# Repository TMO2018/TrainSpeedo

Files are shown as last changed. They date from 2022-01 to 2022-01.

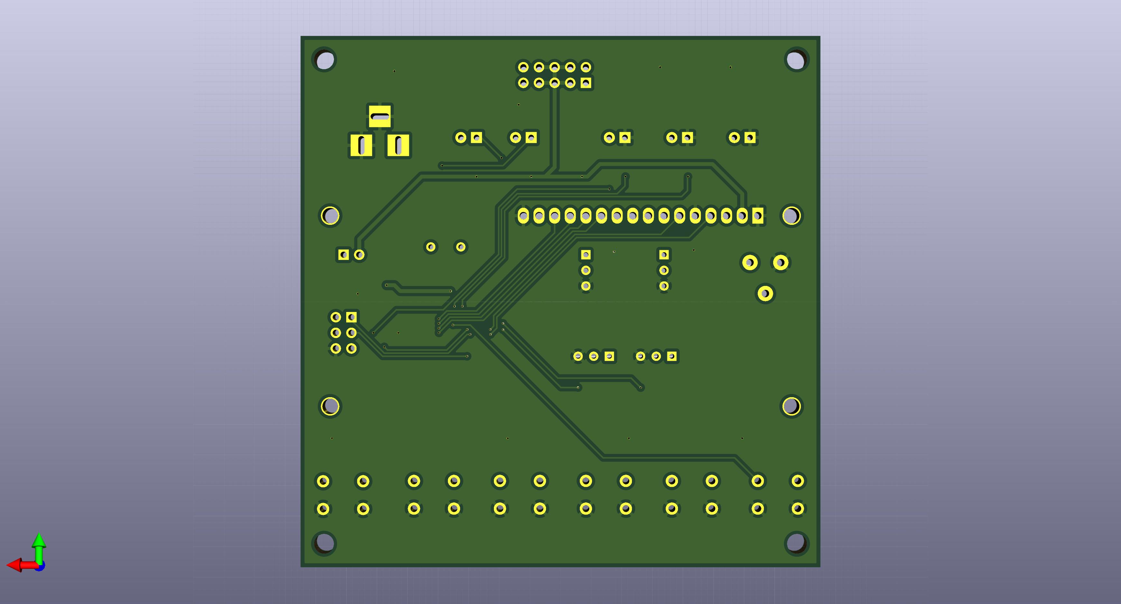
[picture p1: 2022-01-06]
kicad/Rev1_0a/pic/2_back.jpg

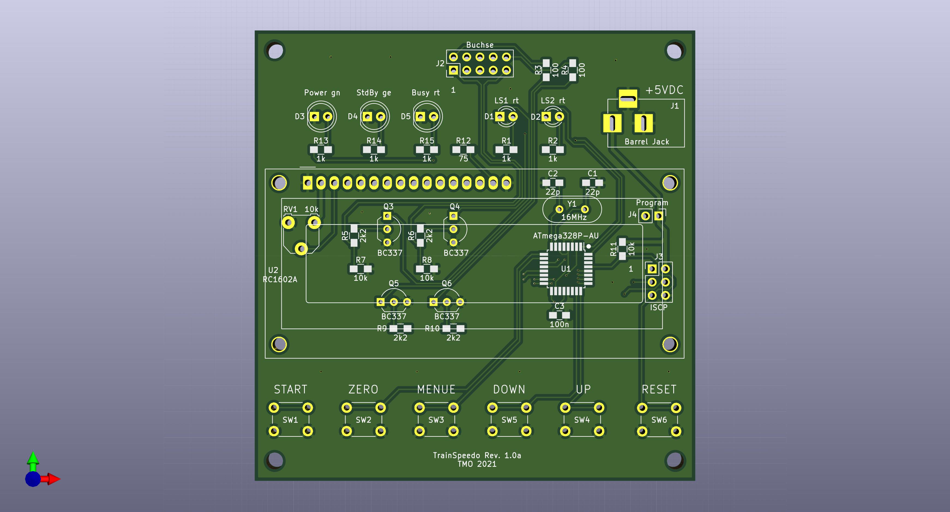
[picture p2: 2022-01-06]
kicad/Rev1_0a/pic/1_front.jpg

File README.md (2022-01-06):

# TrainSpeedo
The project is based on the source:
https://dcc-arduino.weebly.com/scale-speedometer.html

This project is a "real size" speedometer for miniature trains, cars and anything you wish to measure.
It can calculate the speed of the object between 2 measuring points along the track (or road) by counting milliseconds between passages at the start and end gates. If you enter the distance between those gates (in dm) and the used scale (ex. H0 = 1:87) in to the Arduino, it will calculate the actual "real" speed of the object if it were on a 1:1 scale in the real world. This is a useful tool for measuring and calibrating the speed of your model trains on the layout, in order to be able to set and control their speed in the PC or central station for a realistic run on the tracks.

2 detectors are set up along the track, at a known distance (in dm) from each other. When a train runs by one of the detectors, the timer is started, the switch is auto-disabled (to eliminate double counts or other forms of interference) and only when the object passes by the other detector, will the timer be stopped and will the module calculate the speed based on time , distance and scale factors.

Due to the auto-disable fuction of the detectors, the system can calculate either LTR or RTL (left to right or right to left) moving objects with the same accuracy.

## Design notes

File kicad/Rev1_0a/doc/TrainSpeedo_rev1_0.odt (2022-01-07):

TrainSpeedo Rev. 1.0

Description

The project is based on this source:

https://dcc-arduino.weebly.com/scale-speedometer.html

# Introduction

This project is a "real size" speedometer for miniature trains, cars and anything you wish to measure.

It can calculate the speed of the object between 2 measuring points along the track (or road) by counting milliseconds between passages at the start and end gates. If you enter the distance between those gates (in dm) and the used scale (ex. H0 = 1:87) in to the Arduino, it will calculate the actual "real" speed of the object if it were on a 1:1 scale in the real world. This is a useful tool for measuring and calibrating the speed of your model trains on the layout, in order to be able to set and control their speed in the PC or central station for a realistic run on the tracks.

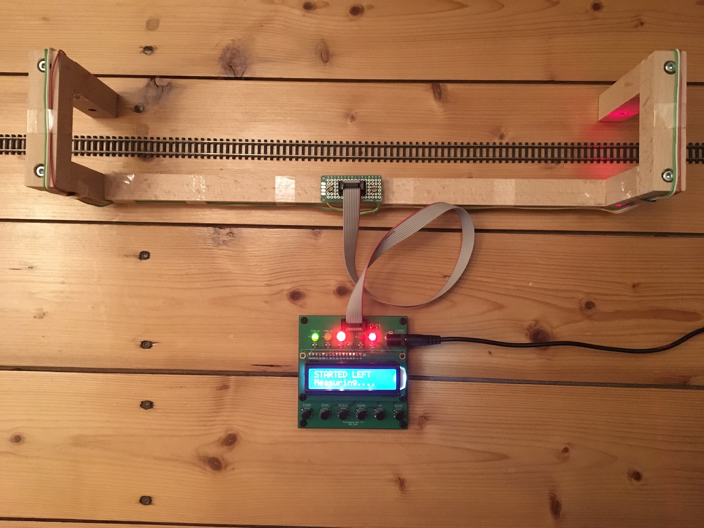
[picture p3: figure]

2 detectors are set up along the track, at a known distance (in dm) from each other. When a train runs by one of the detectors, the timer is started, the switch is auto-disabled (to eliminate double counts or other forms of interference) and only when the object passes by the other detector, will the timer be stopped and will the module calculate the speed based on time , distance and scale factors.

Due to the auto-disable fuction of the detectors, the system can calculate either LTR or RTL (left to right or right to left) moving objects with the same accuracy.

The commands :

-- START button : use this one to trigger the circuit and put it in stand-by so it will start measuring when an boject enters the test track section.

-- ZERO button : to clear the display or to interrupt an ongoing measurement (bypass)

-- MENU button : enters the 3 menu levels

* first push : enter the menu and go to the input screen for track length

* 2nd push : record the current setting and go to screen for scale input

* 3rd push : record the scale factor and go to the confirm / exit screen

* 4th push : confirm and store the new values or return to old ones and then go to main mode. (exit menu)

-- UP / DOWN buttons : used to increment / decrement or change the values in the menu screen.

-- RESET button (optional) : for a full reset of the device (however, scale and length are stored in EEPROM and will be remembered)

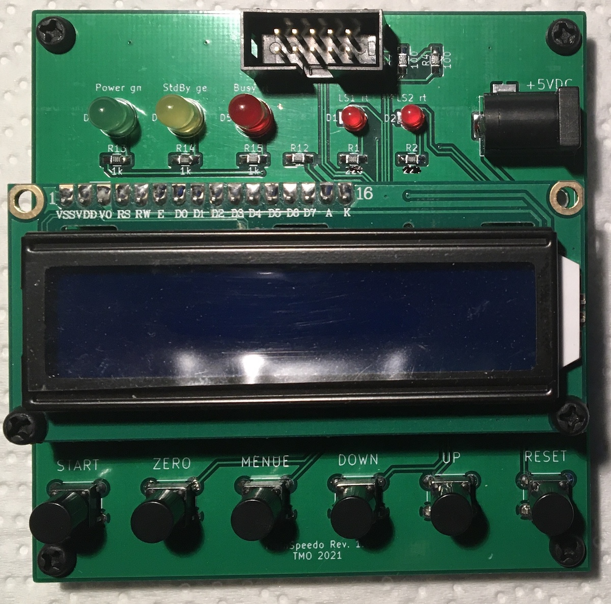
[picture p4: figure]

# Detection

Detection is done using two Laser-LED / Transistor combinations, which create a "light vault" at each end of the measuring track/road.

The swithcing is "to ground" so when an object breaks the beam, the counter will start.

instead of IR vaults, you can also use conventional switches (contact switches), reed switches (magnetic), manual switches (like a stopwatch works) or any kind of detection that can swith a contact to ground.

# Speed conversion formulas

We measure the distance between detectors in dm (decimeters) .

We measure the time in ms (milliseconds).

We measure the scale in units (ex. 87 = scale H0 = 1:87, 160 = Scale N = 1:160) after some calculations (1000 ms in a second -- 1 m/s = 3.6 km/h -- 100 mm in a dm ) here is the formula :

speed (km/h) = 360 * Distance (dm) * Scale (units) / Time (ms)

So a train covering 6 dm in 3838 ms at scale H0 (87) would be going 48 km/h in reality.

BOM

Reference Value Package Part

C1, C2 22p SMD 0805 Ceramic capacitor

C3 100n SMD 0805 Ceramic capacitor

D1, D2 red 3mm THT Led

D3 green 5mm THT Led

D4 yellow 5mm THT Led

D5 red 5mm THT Led

LD1, LD2 red 6x14mm 650nm Laser diode

R1, R2 1k SMD 0805 Resistor

R3, R4 100 SMD 0805 Resistor

R5, R6, R9, R10 2k2 SMD 0805 Resistor

R7, R8, R11 10k SMD 0805 Resistor

R12 75 SMD 0805 Resistor

R13, R14, R15 1k SMD 0805 Resistor

RV1 10k RM-065 THT Trimmer

Q1, Q2 SFH300 5mm THT Phototransistor

Q3, Q4, Q5, Q6 BC337 TO-92 Transistor NPN

SW1, SW2, SW3 6x6x6 mm THT Push-Switch

SW4, SW5, SW6 6x6x6 mm THT Push-Switch

U1 ATmega328-AU TQFP-32 7x7mm pitch 0,8mm Microcontroller

U2 RC1602A Various Display unit

U2 1x16 Female straight RM2,54 Connector

Y1 16MHz HC49-U vertical Crystal

J1 Barrel Jack Female 5,5mm / 2,1mm Connector

J2 2x5 Female straight RM2,54 Connector

J3 2x3 Male straight RM2,54 Connector

J4 1x2 Male straight RM2,54 Connector

J5 2x5 Male straight RM2,54 Connector

# Power supply

A plug-in power supply with output 5VDC 1-3A with a barrel connector 5.5mm / 2.1mm can be used. The positive pole must be on the inside.

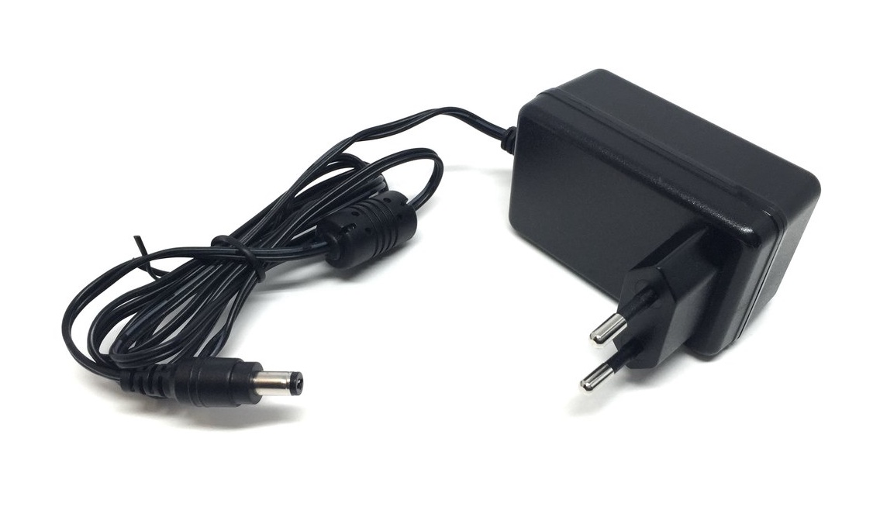
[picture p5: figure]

# Buildung the firmware

The firmware was created with the Arduino software 1.8.15. For this it is necessary to integrate the minicore library into the Arduino software.

https://github.com/MCUdude/MiniCore

The following parameters are to be set in the Tools menu:

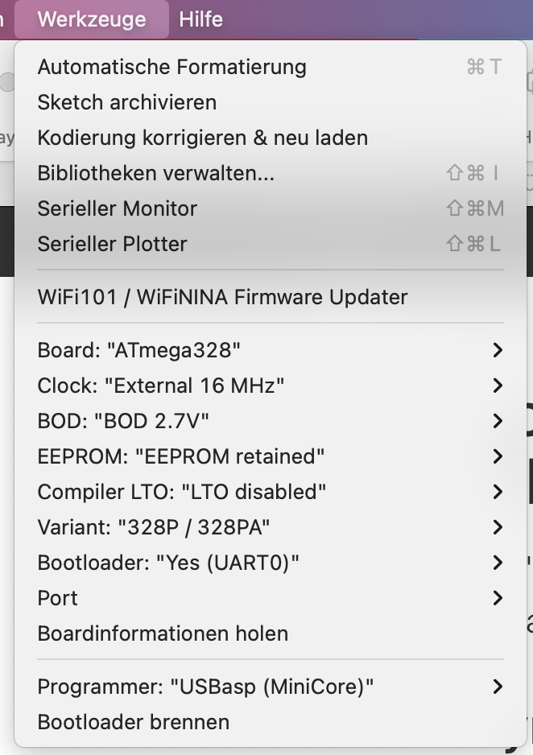
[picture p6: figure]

The next step is to compile and export the firmware in the Sketch menu.

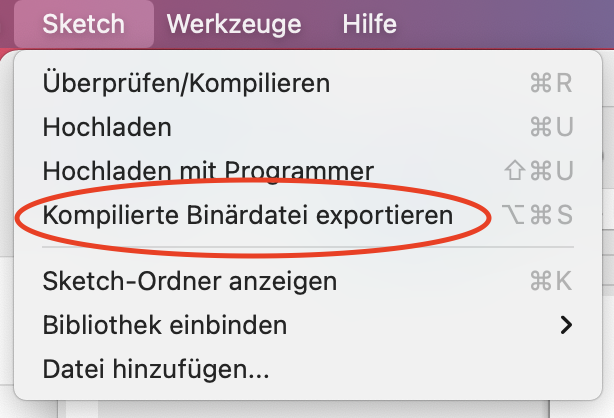
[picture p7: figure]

Now two .hex files have been created. The hex file without bootloader can now be used as a finished firmware and loaded into the Atmega.

# Programming

For programming, the display must be removed and jumper J4 opened.

The ATmega is programmed via the ISCP interface J3. The fuses must be set before programming the firmware.

Fuses:

- EXTENDED: 0xFD

- HIGH: 0xDE

- LOW: 0xF7 -> externer Full.swing Crystal (hier: 16MHz, wie Arduino UNO, NANO)

I used the Pololu Programmer v2.1 with the software AVRFuses 1.5.2 and the Pololu Configuratuins Utility under macos.

# Initial start-up

The contrast of the display can be adjusted with the trimmer RV1 until characters are visible.

Jumper J4 must be closed.

When starting up for the first time or after programming firmware, the model scale and the measuring distance must be set using the MENUE, UP, DOWN buttons.

For example:

Scale:

H0 : 87

N : 160

Measuring distance between the detectors (photoelectric barrier):

4 : 40cm

10 : 100cm

# Release notes :

*1* due to limitations in EEPROM writeable values (0-254) the length of measurement is limited to 254 decimeters, meaning 25,5 M (approx 70 ft) which should cover most purposes. Bear in mind that the speed calculations are done in cm/s but the length of the test track is in dm (decimeters) when you enter it in the menu. All internal conversions are done by the Arduino module.

*2* for wiring and component saving reasons, ALL pull up resistors (internal ones) must be enabled on the input channels.

Revision 1.0:

The following changes are taken into account in revision 1.0a.

1. A bridge from pin 1 to pin 5 must be added to the underside of the board (see picture).

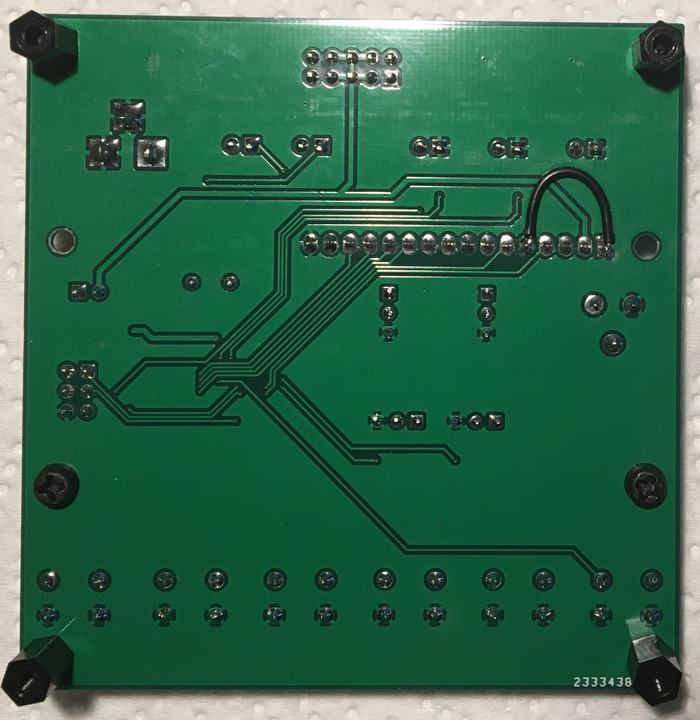
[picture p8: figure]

2. Changed component values C1, C2, R1, R2 and R12 compared to the board labeling.

C1, C2: 22p SMD 0805

R1, R2: 1k SMD 0805

R12: 75 SMD 0805

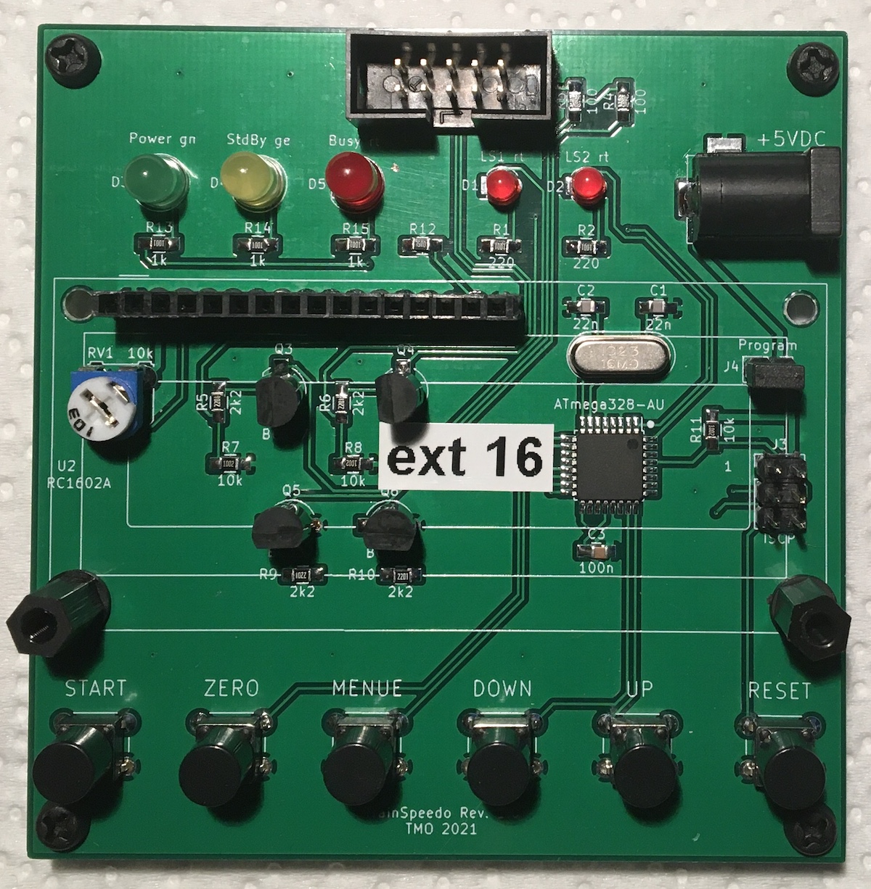
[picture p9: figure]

TrainSpeedo_rev1_0.odt 06.01.2022 Page 7 of 7 TMO Version 1.0

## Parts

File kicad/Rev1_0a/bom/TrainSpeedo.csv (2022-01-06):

Source | /Users/Tom/Documents/KiCad/Projekte/TrainSpeedo/Rev1_0/TrainSpeedo.sch
Kicad Rev | Eeschema (5.1.10-1-10_14)
Generated Date | Donnerstag | 06. Januar 2022 um 11:17:52
Title | TrainSpeedo
Company | TMO
Revision | 1.0
Date Issue | 2021-11-11
Reference | Value | Library | Library Ref
U1 | ATmega328-AU | MCU_Microchip_ATmega | ATmega328-AU
U2 | RC1602A | Display_Character | RC1602A
LD1 | Laserdiode1 | Device | Laserdiode_1C2A
Q1 | SFH300 | Sensor_Optical | SFH300
D3 | Power gn | Device | LED
D4 | StdBy ge | Device | LED
D5 | Busy rt | Device | LED
RV1 | 10k | Device | R_POT
R13 | 1k | Device | R
R14 | 1k | Device | R
R15 | 1k | Device | R
R11 | 10k | Device | R
SW3 | MENUE | Switch | SW_Push
SW2 | ZERO | Switch | SW_Push
SW1 | START | Switch | SW_Push
SW4 | UP | Switch | SW_Push
SW5 | DOWN | Switch | SW_Push
Y1 | 16MHz | Device | Crystal
C1 | 22n | Device | C
C2 | 22n | Device | C
R12 | ? | Device | R
Q6 | BC337 | Transistor_BJT | BC337
Q4 | BC337 | Transistor_BJT | BC337
LD2 | Laserdiode2 | Device | Laserdiode_1C2A
Q2 | SFH300 | Sensor_Optical | SFH300
D2 | LS2 rt | Device | LED
R2 | 220 | Device | R
R6 | 2k2 | Device | R
R8 | 10k | Device | R
R4 | 100 | Device | R
SW6 | RESET | Switch | SW_Push
R10 | 2k2 | Device | R
J2 | Buchse | Connector_Generic | Conn_02x05_Odd_Even
R9 | 2k2 | Device | R
R3 | 100 | Device | R
R7 | 10k | Device | R
R5 | 2k2 | Device | R
R1 | 220 | Device | R
D1 | LS1 rt | Device | LED
Q3 | BC337 | Transistor_BJT | BC337
Q5 | BC337 | Transistor_BJT | BC337
J5 | Stecker | Connector_Generic | Conn_02x05_Odd_Even
J1 | Barrel Jack | Connector | Conn_01x03_Female
J3 | ISCP | Connector_Generic | Conn_02x03_Odd_Even
J4 | Program | Connector_Generic | Conn_01x02
C3 | 100n | Device | C
H1 | MountingHole | Mechanical | MountingHole
H2 | MountingHole | Mechanical | MountingHole
H3 | MountingHole | Mechanical | MountingHole
H4 | MountingHole | Mechanical | MountingHole

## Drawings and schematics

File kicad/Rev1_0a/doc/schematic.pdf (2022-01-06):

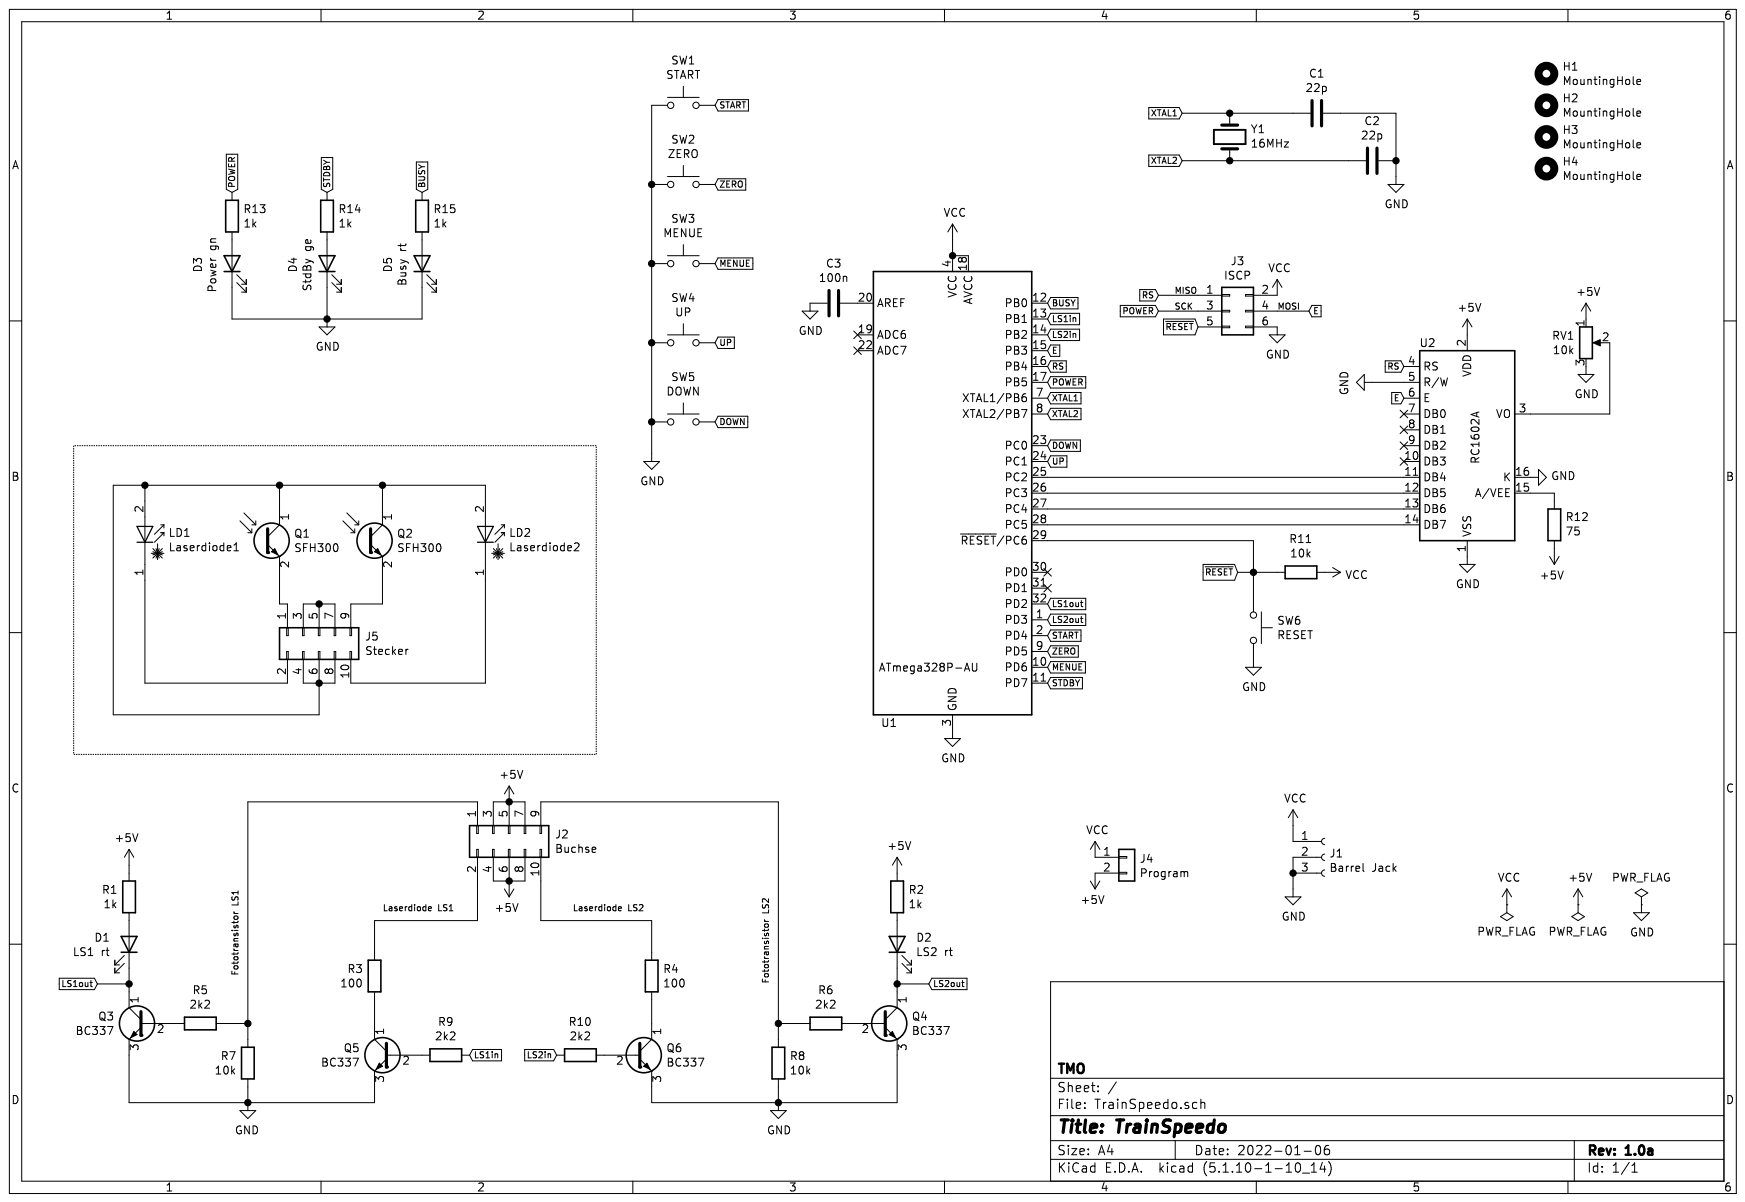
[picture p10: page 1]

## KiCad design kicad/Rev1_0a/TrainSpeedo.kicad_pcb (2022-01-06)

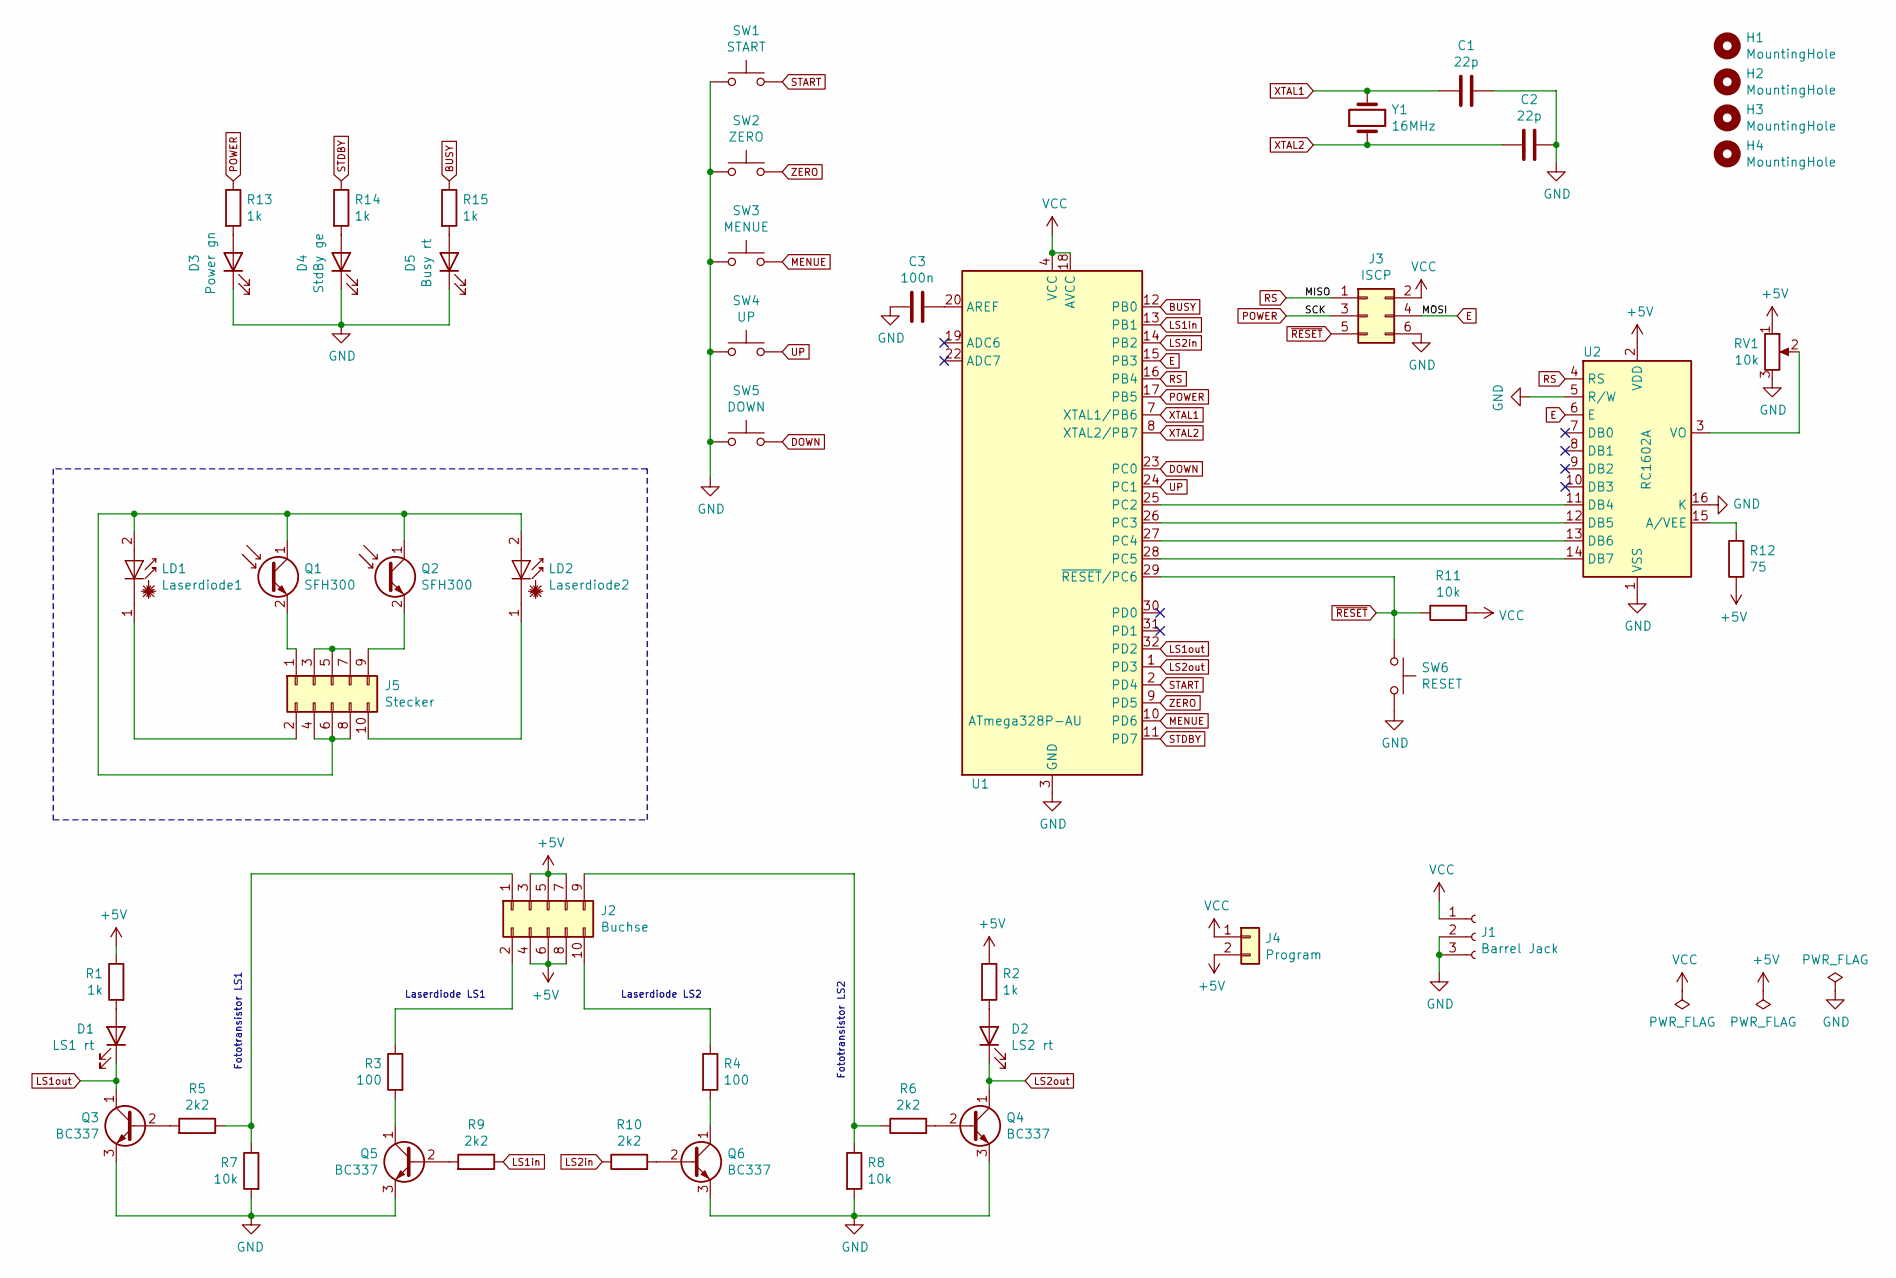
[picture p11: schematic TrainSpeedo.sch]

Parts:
C1, C2: 22p; C_0805_HandSoldering
C3: 100n; C_0805_HandSoldering
D1: LS1 rt; LED_D3.0mm
D2: LS2 rt; LED_D3.0mm
D3: Power gn; LED_D5.0mm
D4: StdBy ge; LED_D5.0mm
D5: Busy rt; LED_D5.0mm
H1, H2, H3, H4: MountingHole; MountingHole_3.2mm_M3
J1: Barrel Jack; BARREL_JACK
J2: Buchse; Pin_Header_Straight_2x05_Pitch2.54mm
J3: ISCP; Pin_Header_Straight_2x03_Pitch2.54mm
J4: Program; Pin_Header_Straight_1x02_Pitch2.54mm
J5: Stecker
LD1: Laserdiode1
LD2: Laserdiode2
Q1, Q2: SFH300
Q3, Q4, Q5, Q6: BC337; TO-92_Inline_Wide
R1, R2, R13, R14, R15: 1k; R_0805_HandSoldering
R3, R4: 100; R_0805_HandSoldering
R5, R6, R9, R10: 2k2; R_0805_HandSoldering
R7, R8, R11: 10k; R_0805_HandSoldering
R12: 75; R_0805_HandSoldering
RV1: 10k; Potentiometer_Triwood_RM-065
SW1: START; SW_PUSH_6mm
SW2: ZERO; SW_PUSH_6mm
SW3: MENUE; SW_PUSH_6mm
SW4: UP; SW_PUSH_6mm
SW5: DOWN; SW_PUSH_6mm
SW6: RESET; SW_PUSH_6mm
U1: ATmega328P-AU; TQFP-32_7x7mm_Pitch0.8mm
U2: RC1602A; WC1602A
Y1: 16MHz; Crystal_HC49-U_Vertical

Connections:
+5V: J2.3, J2.4, J2.5, J2.6, J2.7, J2.8, J4.2, R1.1, R2.1, R12.1, RV1.1, U2.2 (VDD)
BUSY: R15.1, U1.12 (PB0)
DOWN: SW5.2, U1.23 (PC0)
E: J3.4, U1.15 (PB3), U2.6 (E)
GND: C1.1, C2.1, C3.2, D3.1 (K), D4.1 (K), D5.1 (K), J1.2, J1.3, J3.6, Q3.3 (E), Q4.3 (E), Q5.3 (E), Q6.3 (E), R7.2, R8.2, RV1.3, SW1.1, SW2.1, SW3.1, SW4.1, SW5.1, SW6.2, U1.3 (GND), U1.5 (GND), U1.21 (GND), U2.1 (VSS), U2.5 (R/W), U2.16 (K)
LS1in: R9.1, U1.13 (PB1)
LS1out: D1.1 (K), Q3.1 (C), U1.32 (PD2)
LS2in: R10.1, U1.14 (PB2)
LS2out: D2.1 (K), Q4.1 (C), U1.1 (PD3)
MENUE: SW3.2, U1.10 (PD6)
unnamed: C3.1, U1.20 (AREF)
unnamed: D1.2 (A), R1.2
unnamed: D2.2 (A), R2.2
unnamed: D3.2 (A), R13.2
unnamed: D4.2 (A), R14.2
unnamed: D5.2 (A), R15.2
unnamed: J2.1, R5.1, R7.1
unnamed: J2.2, R3.1
unnamed: J2.9, R6.1, R8.1
unnamed: J2.10, R4.1
unnamed: J5.1, Q1.2 (E)
unnamed: J5.2, LD1.1 (K)
unnamed: J5.3, J5.5, J5.7
unnamed: J5.4, J5.6, J5.8, LD1.2 (A), LD2.2 (A), Q1.1 (C), Q2.1 (C)
unnamed: J5.9, Q2.2 (E)
unnamed: J5.10, LD2.1 (K)
unnamed: Q3.2 (B), R5.2
unnamed: Q4.2 (B), R6.2
unnamed: Q5.1 (C), R3.2
unnamed: Q5.2 (B), R9.2
unnamed: Q6.1 (C), R4.2
unnamed: Q6.2 (B), R10.2
unnamed: R12.2, U2.15 (A/VEE)
unnamed: RV1.2, U2.3 (VO)
unnamed: U1.25 (PC2), U2.11 (DB4)
unnamed: U1.26 (PC3), U2.12 (DB5)
unnamed: U1.27 (PC4), U2.13 (DB6)
unnamed: U1.28 (PC5), U2.14 (DB7)
POWER: J3.3, R13.1, U1.17 (PB5)
RS: J3.1, U1.16 (PB4), U2.4 (RS)
START: SW1.2, U1.2 (PD4)
STDBY: R14.1, U1.11 (PD7)
UP: SW4.2, U1.24 (PC1)
VCC: J1.1, J3.2, J4.1, R11.2, U1.4 (VCC), U1.6 (VCC), U1.18 (AVCC)
XTAL1: C1.2, U1.7 (XTAL1/PB6), Y1.2
XTAL2: C2.2, U1.8 (XTAL2/PB7), Y1.1
ZERO: SW2.2, U1.9 (PD5)
~RESET: J3.5, R11.1, SW6.1, U1.29 (~RESET~/PC6)

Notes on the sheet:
Fototransistor LS1
Fototransistor LS2
Laserdiode LS1
Laserdiode LS2

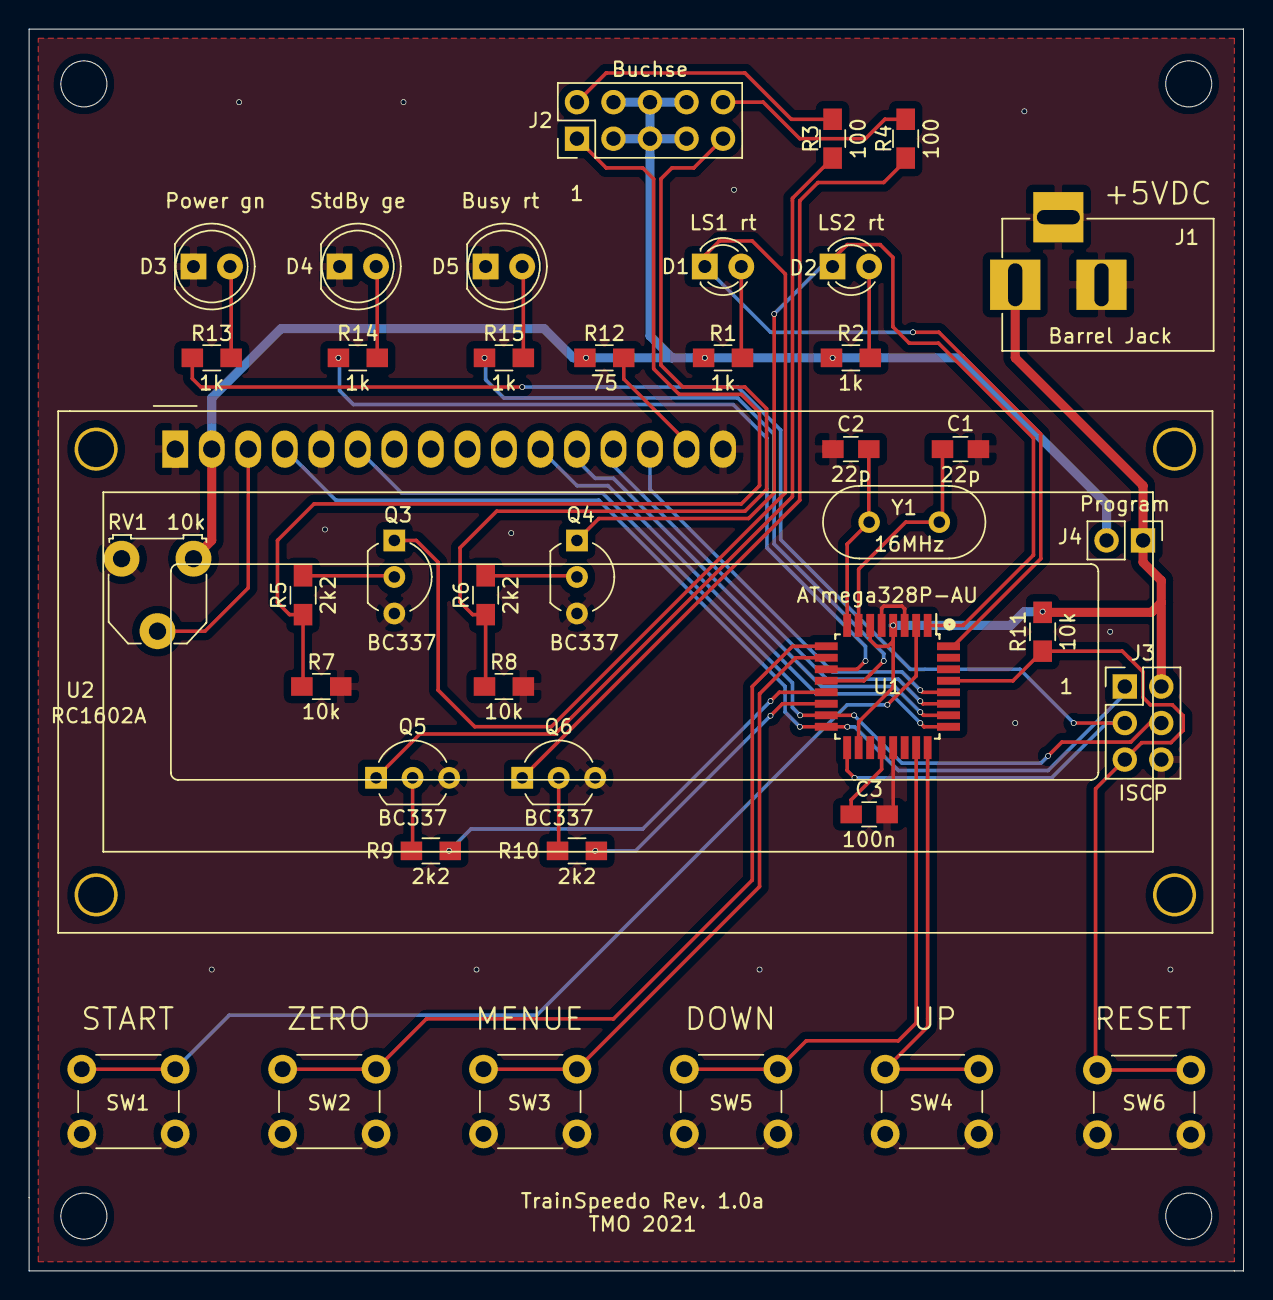
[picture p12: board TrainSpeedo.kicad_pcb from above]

Board: 2 copper layers, 84.5 x 86.4 mm, 45 parts (0 on the bottom side), 42 nets.

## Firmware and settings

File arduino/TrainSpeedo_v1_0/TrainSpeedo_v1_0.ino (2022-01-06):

int Version = 2;

/*
  Trainspeed calculator.
  
  This uses 2 inputs from IR LED / IR receivers and measures the speed of a train over a certain track length
  
  Note on the inputs :   The IR receivers will switch the corresponding inputs to GND when they detect IR light
                           so these must be triggered on  "HIGH"  value (meaning a train is blocking the path between
                           IR LED (sender) and IR  transistor (receiver).   However, the push buttons will switch on
                           negative  (connectin to ground) because of having the pullup resistors enabled.  This
                           avoids having to solder in  pull-down resistors on all these channels.
   
--COMMUNICATION
  D0 =  serial comm
  D1 =  serial comm

--INPUTS.
  D2 =  IR sensor 1  (int 0)     -- PULLUP !!
  D3 =  IR sensor 2  (int 1)     -- PULLUP !!
  D4 =  Start measuring (armed)  -- PULLUP !!
  D5 =  Reset to zero            -- PULLUP !!
  D6 =  Settings menu            -- PULLUP !!
  A0 =  Setting UP               -- PULLUP !!
  A1 =  Setting DOWN             -- PULLUP !!
  
--OUTPUTS 
  D7 =  StandBy / Ready LED (blue)
  D8 =  Busy LED  (blinking)
  D9 =  IR LED 1
  D10 = IR LED 2
  D11 = LCD RS
  D12 = LCD ENable
  D13=  Power LED  (red)
  A2  = LCD D4
  A3  = LCD D5
  A4  = LCD D6
  A5  = LCD D7  
  
 */

/* speed conversion formulas  

-- a train in scale 1:X  takes  Y seconds  to run   Z   cm of track
=> his scale speed is    Z / Y       cm/sec
=> he runs               Z/(100*y)   m/sec
1 m/sec corresponds to 3600 m per hour 
this equals 3,6 km per hour
==>  his scale speed is then     Z *  3,6  /  (100 * y)   km/h
1 cm on scale 1:X   would be     X cm in the real world
==>   The train's converted  "real" speed is  then expressed by the formula  
         X * Z * 3,6 / (100 * Y)    km/h 

An example  =    train in scale 1:87  does   3 meters (300 cm)  in  20 seconds
==>  his speed is   (87 * 300 *  3,6 / (100 * 20 )  =  93960 / 2000 = 47  km/h 

On the Arduino, we measure the time difference in milliseconds.   (time / 1000)
Conclusion: the formula =  
      SpeedKmh =  3.6 * Scale * Length / (100 * Delta/1000 )

The example  :  
     SpeedKmh = 3.6 * 87 * 300 / (100 * 20000 / 1000 ) = 93960 / 2000 = 47 km/h
*/

//  Libraries and  declarations
#include <LiquidCrystal.h>
#include <EEPROM.h>


// GLOBAL PROGRAM VARIABLES
int Length = 4;              // default 1 meter = 4x10 cm  -- will read from eeprom
int Scale  =  160;             // default N scale  1:160      -- will read from eeprom
int SpeedKmh = 0;             // calculated speed in km per hour
int Conversion = 0;           // conversion factor based on EEprom values
int Trigger_RL = 0;           // 0=no motion   1=Left triggered     2=right triggered
int MenuStep = 0;             // Menu step 0=none  1= scale  2 = Speed
unsigned long Start  = 0;     // milliseconds at start
unsigned long Finish = 0;     // milliseconds at end
unsigned long Delta= 0;       // timed milliseconds
unsigned long RealKmh = 0;
boolean Running = false;      // measurement ongoing
boolean Armed   = false;      // not ready
boolean Sensor1On = false;    // enable or disable IR sensor 1 (left)
boolean Sensor2On = false;    // enable or disable IR sensor 2 (right)
boolean MenuMode = false;      // enable or disable menu mode

// TMO
int Taste_DOWN = A1;
int Taste_UP   = A0;

// initialize the library with the numbers of the interface pins
LiquidCrystal LCD(12, 11, A2, A3, A4, A5);
           //     RS  EN  D4  D5  D6  D7 


void setup() {
  pinMode(13,OUTPUT);

  pinMode(A2,OUTPUT);
  pinMode(A3,OUTPUT);
  pinMode(A4,OUTPUT);
  pinMode(A5,OUTPUT);
  
  digitalWrite(13,HIGH);
  Serial.begin(9600);
  Serial.println("Initializing");
  Serial.print("Version  3.");Serial.println(Version);
  // set up the LCD's number of columns and rows: 
  Serial.println("Setup LCD");
  digitalWrite(13,LOW);
  LCD.begin(16, 2);
  LCD.display();
  LCD.clear();
 digitalWrite(13,HIGH);
 // Print a message to the LCD.
  LCD.clear();LCD.print("Train Speedo");
  delay(1000);
  // read scale and track length from EEPROM
  Serial.println("Retrieve EEPROM data");
  Length = EEPROM.read(1);  // max 255 = 2550 cm = 25,5 meters
  Serial.print("Measuring track length in dm = ");Serial.println(Length);
  Scale  = EEPROM.read(2);
  Serial.print("Measuring scale = 1:");Serial.println(Scale);
  Serial.println("Establishing Calculating conversion factor");
  Serial.println("dm/ms -> km/h  =   3,6 x distance(dm) x scale(S) / Time(mSec) ");
  RealKmh=3.6 *Scale * 20 / 200;
  SpeedKmh=int(RealKmh);
  Serial.print("36 x "); Serial.print(Scale); Serial.println(" x 20 / 2000");
  Serial.println(RealKmh);
  Serial.println(SpeedKmh);
  //   
  LCD.clear();LCD.print("Initializing");delay(500);
  Serial.println("Setting Output channels");
  pinMode(7,OUTPUT);
  pinMode(8,OUTPUT);
  pinMode(9,OUTPUT);
  pinMode(10,OUTPUT);
  pinMode(11,OUTPUT);
  pinMode(12,OUTPUT);

  Serial.println("Setting Output channels and enabling internal Pull Up resistors");
  pinMode(2 ,INPUT_PULLUP);
  pinMode(3 ,INPUT_PULLUP);
  pinMode(4 ,INPUT_PULLUP);
  pinMode(5 ,INPUT_PULLUP);
  pinMode(6 ,INPUT_PULLUP);
  pinMode(A0,INPUT_PULLUP);
  pinMode(A1,INPUT_PULLUP);
  Serial.println("Attaching interrupts");
//  attachInterrupt(0, LeftDetect, RISING);
//  attachInterrupt(1, RightDetect, RISING);
  Serial.println("Setting variables");
  Armed=false;
  Running=false;
  Sensor1On=false;
  Sensor2On=false;
  MenuMode=false;
  LCD.clear();LCD.print("Starting");delay(500);
  digitalWrite( 7,LOW);
  digitalWrite( 8,LOW);
  digitalWrite( 9,LOW);
  digitalWrite(10,LOW);
  digitalWrite(13,HIGH);
  LCD.clear();
  LCD.setCursor(0,0);LCD.write("System Ready");
  LCD.setCursor(0,1);LCD.write("Press ** GO ** ");
  Serial.println("Initialisation OK");
  Serial.println("Press  START  button to initiate measurement ");
  
}

////////////////////////////////////////////////////////////////////////////////////////////
//  MAIN ROUTINE
////////////////////////////////////////////////////////////////////////////////////////////


// the loop routine runs over and over again forever:
void loop() 

{

//  if system is armed, check for passage at either IR detectors
if (Armed) // run this only when a measurement is requested 
  {digitalWrite(7,HIGH);digitalWrite(8,LOW);
   if (digitalRead( 2))   // Sensor 1
    {LeftStart();goto EndLoop;}
   if (digitalRead( 3))    // Sensor 2 
    {RightStart();goto EndLoop;}   }  

//  if system is measuring, check for passage at either IR detectors
if (Running) // run this only when a measurement is ongoing
  {digitalWrite(7,LOW);digitalWrite(8,HIGH);
   if (digitalRead( 2) && Sensor1On) {LeftStop();goto EndLoop;}    // Sensor 1
   if (digitalRead( 3) && Sensor2On) {RightStop();goto EndLoop;} } // Sensor 2 
 
// reset and request  buttons   
if (!digitalRead( 5)) {ResetSystem();goto EndLoop;}                 // Reset
if (!digitalRead( 4) && !Armed ) {ArmSystem(); goto EndLoop;}       // Activate
  
//  menu for setting distance and scale  
if (!digitalRead( 6))    // MENU Select
  {Serial.println("D6  to ground");
   MenuMode=true;
   ProcessMenu();
   goto EndLoop;}
   
if (!digitalRead(A0)) {Serial.println("A0  to ground");}   // MENU +
if (!digitalRead(A1)) {Serial.println("A1  to ground");}   // MENU -



EndLoop:   // resume from start
DoNothing();

}

/////////////////////////////////////////////////////////////////////////////////
//  Set all variables and arm the system
/////////////////////////////////////////////////////////////////////////////////
void ArmSystem()
{ Serial.println("D4  to ground");
  Serial.println("System armed");
  Trigger_RL  = 0;
  Armed       = true;  
  Running     = false;
  Serial.println("Setting IR LEDs");
  digitalWrite(9,HIGH);
  digitalWrite(10,HIGH);  
  Serial.println("Setting Status LEDs");
  digitalWrite(13,HIGH);  // power
  digitalWrite( 7,HIGH);  // armed
  digitalWrite( 8,LOW );  // busy}
  Serial.println("Setting sensors");
  Sensor1On = true;
  Sensor2On = true;
  Start  = 0;
  Finish = 0;
  Delta  = 0;
  LCD.clear();
  LCD.setCursor(0,0);LCD.write("*** STARTED ***");
  LCD.setCursor(0,1);LCD.write("Wait for Signal");
 }
 
/////////////////////////////////////////////////////////////////////////////////
//  Reset system
/////////////////////////////////////////////////////////////////////////////////
void ResetSystem()
{ Serial.println("System Reset");
  digitalWrite(13,HIGH);  // power
  digitalWrite( 7,HIGH );  // armed
  digitalWrite( 8,HIGH );  // busy
  LCD.clear();
  LCD.setCursor(0,0);LCD.write("** R E S E T **");
  LCD.setCursor(0,1);LCD.write("Please hold....");
  Trigger_RL  = 0;
  Armed       = false;  
  Running     = false;
  Serial.println("Resetting IR LEDs");
  digitalWrite(9,LOW);
  digitalWrite(10,LOW);
  Serial.println("Setting Status LEDs");
  Serial.println("Setting sensors");
  Sensor1On = false;
  Sensor2On = false;
  Start  = 0;
  Finish = 0;
  Delta  = 0;
  delay(2000);
  LCD.clear();
  LCD.setCursor(0,0);LCD.write("System Ready");
  LCD.setCursor(0,1);LCD.write("Press ** GO ** ");
  digitalWrite(13,HIGH);  // power
  digitalWrite( 7,LOW );  // armed
  digitalWrite( 8,LOW );  // busy
  // soft reset
  asm volatile ("  jmp 0");
  
}


/////////////////////////////////////////////////////////////////////////////////
//  LeftStart   interrupt routine   on pin  D2  - IRQ 0
/////////////////////////////////////////////////////////////////////////////////
void LeftStart()
{ // left sensor linked to  IR  LED 1
  Serial.println("D2  to ground");
  Serial.println("LeftStart triggered");
  Trigger_RL=1;
  Serial.println("Disabling left sensor 1");
  Sensor1On = false;  
  Sensor2On = true;  
  Armed=false;
  Running=true;
  digitalWrite(7,LOW);  
  digitalWrite(8,HIGH);
  
  digitalWrite(9,LOW);  
  digitalWrite(10,HIGH);
  
  Start  = millis();
  Finish = 0;
  Delta  = 0;
  LCD.clear();
  LCD.setCursor(0,0);LCD.write("STARTED LEFT");
  LCD.setCursor(0,1);LCD.write("Measuring....");

}


/////////////////////////////////////////////////////////////////////////////////
//  RightStart   interrupt routine   on pin  D3  - IRQ 1
/////////////////////////////////////////////////////////////////////////////////
void RightStart()
{ // right sensor linked to  IR  LED 1
  Serial.println("D3  to ground");
  Serial.println("RightStart triggered");
  Trigger_RL=2;
  Serial.println("Disabling right sensor 2");
  Sensor1On = true;    
  Sensor2On = false;  
  Armed=false;
  Running=true;
  digitalWrite(7,LOW);  
  digitalWrite(8,HIGH);
  digitalWrite(10,LOW);  
  digitalWrite(9,HIGH);
  
  Start  = millis();
  Finish = 0;
  Delta  = 0;
  LCD.clear();
  LCD.setCursor(0,0);LCD.write("STARTED RIGHT");
  LCD.setCursor(0,1);LCD.write("Measuring....");
}


/////////////////////////////////////////////////////////////////////////////////
//  RightStop   interrupt routine   on pin  D3  - IRQ 1
/////////////////////////////////////////////////////////////////////////////////
void RightStop()
{ // right sensor linked to  IR  LED 2
  LCD.setCursor(0,1);LCD.write("STOPPED");
  Serial.println("D3  to ground");
  Serial.println("RightStop triggered");
  Finish = millis();
  CalculateSpeed();
}

/////////////////////////////////////////////////////////////////////////////////
//  LeftStop   interrupt routine   on pin  D2  - IRQ 0
/////////////////////////////////////////////////////////////////////////////////
void LeftStop()
{ // right sensor linked to  IR  LED 1
  LCD.setCursor(0,1);LCD.write("STOPPED");
  Serial.println("D2  to ground");
  Serial.println("LeftStop triggered");
  Finish = millis();
  CalculateSpeed();
}


/////////////////////////////////////////////////////////////////////////////////
//  CalculateSpeed()
/////////////////////////////////////////////////////////////////////////////////
void CalculateSpeed()
{
  unsigned long  snel=0;
  
  digitalWrite(13,LOW);  
  Serial.println("Disabling both sensors");
  Sensor1On = false;    
  Sensor2On = false;  
  Serial.println("Setting system variables");
  Trigger_RL=0;
  Armed=false;
  Running=false;
  digitalWrite( 7,LOW);
  digitalWrite( 8,LOW);  
  digitalWrite( 9,LOW);  
  digitalWrite(10,LOW);  
  Serial.println("Calculating");
  Delta    = Finish-Start;      //elaopsed times in milliseconds.
  RealKmh  = 360 * Length;       Serial.print("Step 1 - 3,6 * Length   : ");Serial.println(RealKmh);
  RealKmh  = RealKmh * Scale;    Serial.print("Step 2 - speed * Scale  : ");Serial.println(RealKmh);
  RealKmh  = RealKmh / Delta;    Serial.print("Step 3 - speed /Delta   : ");Serial.println(RealKmh);
  SpeedKmh = int(RealKmh);
  snel= 360 * Length * Scale / Delta ;  Serial.print ("Alternate : ");Serial.println(int(snel));
  
  Serial.println("Displaying");
  LCD.clear();
  LCD.setCursor(0,0);LCD.write("Time:");
  LCD.setCursor(7,0);LCD.print(Delta);
  LCD.setCursor(0,1);LCD.write("km/h=");
  LCD.setCursor(7,1);LCD.print(SpeedKmh);
  Serial.print("Length = ");Serial.print(Length);Serial.println(" dm");
  Serial.print("Time   = ");Serial.print(Delta);Serial.println(" mSec");
  Serial.print("Scale  = ");Serial.print(Scale);Serial.println(" factor");
  Serial.print("Km/h   = ");Serial.print(SpeedKmh);Serial.println(" km/h");
  digitalWrite(13,HIGH);  
}

/////////////////////////////////////////////////////////////////////////////////
//  ProcessMenu
/////////////////////////////////////////////////////////////////////////////////
void ProcessMenu()
{ 
//  at first  push, enter menu mode 1  (set scale)
//  at second push, enter menu mode 2  (set length)
//  at third  push, enter menu mode 3  (save or cancel)
//  at fourth push, enter menu mode 0  (stop)

int tmpScale =  Scale;
int tmpLength = Length;
boolean Pressed = false;
boolean Accept = false; 

MenuMode=true;
MenuStep=1;

        Serial.print("Select Scale :");Serial.println(tmpScale);
        LCD.clear();
        LCD.setCursor(0,0);LCD.write("Scale : ");
        LCD.setCursor(10,0);LCD.print(tmpScale);
        delay(500);
        // check for buttons and act 
        Pressed=false;
        do {if ( !digitalRead(6))  {Pressed=true;delay(500);}
            if ( !digitalRead(Taste_DOWN)) 
                     {delay(200);tmpScale=tmpScale+1;
                      if(tmpScale>240) {tmpScale=240;}
                      Serial.println(tmpScale);
                      LCD.setCursor(10,0);LCD.write("     ");LCD.setCursor(10,0);LCD.print(tmpScale);}
            if ( !digitalRead(Taste_UP)) 
                     {delay(200);tmpScale=tmpScale-1;
                      if(tmpScale<1)   {tmpScale=1;}
                      Serial.println(tmpScale);
                      LCD.setCursor(10,0);LCD.write("     ");LCD.setCursor(10,0);LCD.print(tmpScale);}
           } while (!Pressed);


        Serial.print("Select Length :");Serial.println(tmpLength);
        LCD.setCursor(0,1);LCD.write("Length : ");
        LCD.setCursor(10,1);LCD.print(tmpLength);
        // check for buttons and act 
        delay(500);
        Pressed=false;
        do {if ( !digitalRead(6))  {Pressed=true;delay(500);}
            if ( !digitalRead(Taste_DOWN)) 
             {delay(200);tmpLength=tmpLength+1;
              if(tmpLength>200) {tmpLength=200;}
              Serial.println(tmpLength);
              LCD.setCursor(10,1);LCD.write("     ");LCD.setCursor(10,1);LCD.print(tmpLength);}
            if ( !digitalRead(Taste_UP)) 
              {delay(200);tmpLength=tmpLength-1;
               if(tmpLength<1)   {tmpLength=1;}
               Serial.println(tmpLength);
               LCD.setCursor(10,1);LCD.write("     ");LCD.setCursor(10,1);LCD.print(tmpLength);}
           } while (!Pressed);
           delay(500);

        Serial.print("Confirm or Cancel :");Serial.println("Y/N");
        Accept=true;
        LCD.clear();
        LCD.setCursor(1,0);LCD.write("Action : ");
        LCD.setCursor(1,10);LCD.write("ACCEPT");
        // check for buttons and act 
        delay(500);
        Pressed=false;
        Serial.println("Accept");
        do {if ( !digitalRead(6))  {Pressed=true;delay(500);}
            if ( !digitalRead(Taste_DOWN)) {Accept=!Accept;delay(200);
                   if (Accept)
                       {LCD.setCursor(1,10);LCD.write("ACCEPT");Serial.println("Accept");}
                   else
                       {LCD.setCursor(1,10);LCD.write("REJECT");Serial.println("Reject");}}
            if ( !digitalRead(Taste_UP)) {Accept=!Accept;delay(200);
                   if (Accept)
                       {LCD.setCursor(1,10);LCD.write("ACCEPT");Serial.println("Accept");}
                   else
                       {LCD.setCursor(1,10);LCD.write("REJECT");Serial.println("Reject");}}
           } while (!Pressed);
        if (Accept) {// save to EEPROM and update memory.
          Serial.println("Writing values to memory and udpating ");
          Length=tmpLength;EEPROM.write(1,int(Length));
          Scale=tmpScale;EEPROM.write(2,Scale);}
          LCD.clear();
          LCD.setCursor(0,0);LCD.write("System Ready");
          LCD.setCursor(0,1);LCD.write("Press ** GO **");
          Serial.println("Done saving values.  ready for next action");
     
}


/////////////////////////////////////////////////////////////////////////////////
//  DoNothing
/////////////////////////////////////////////////////////////////////////////////
void DoNothing()
{ /// absolutely NUTTIN'
}
